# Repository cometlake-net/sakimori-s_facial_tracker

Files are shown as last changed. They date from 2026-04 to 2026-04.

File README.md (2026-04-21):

## License

This hardware design project (including schematics, PCB layout, and routing) is released under the **MIT License**. See the `LICENSE` file for details.

### Third-Party Assets / Acknowledgements

Some component libraries (schematic symbols, footprints, and 3D models) used in this project are provided by [SnapMagic](https://www.snapmagic.com/) (formerly SnapEDA). These specific asset files are licensed under the **Creative Commons Attribution-ShareAlike 4.0 International (CC-BY-SA 4.0)**. 
Please refer to their terms of service for further redistribution or modification of these library files.

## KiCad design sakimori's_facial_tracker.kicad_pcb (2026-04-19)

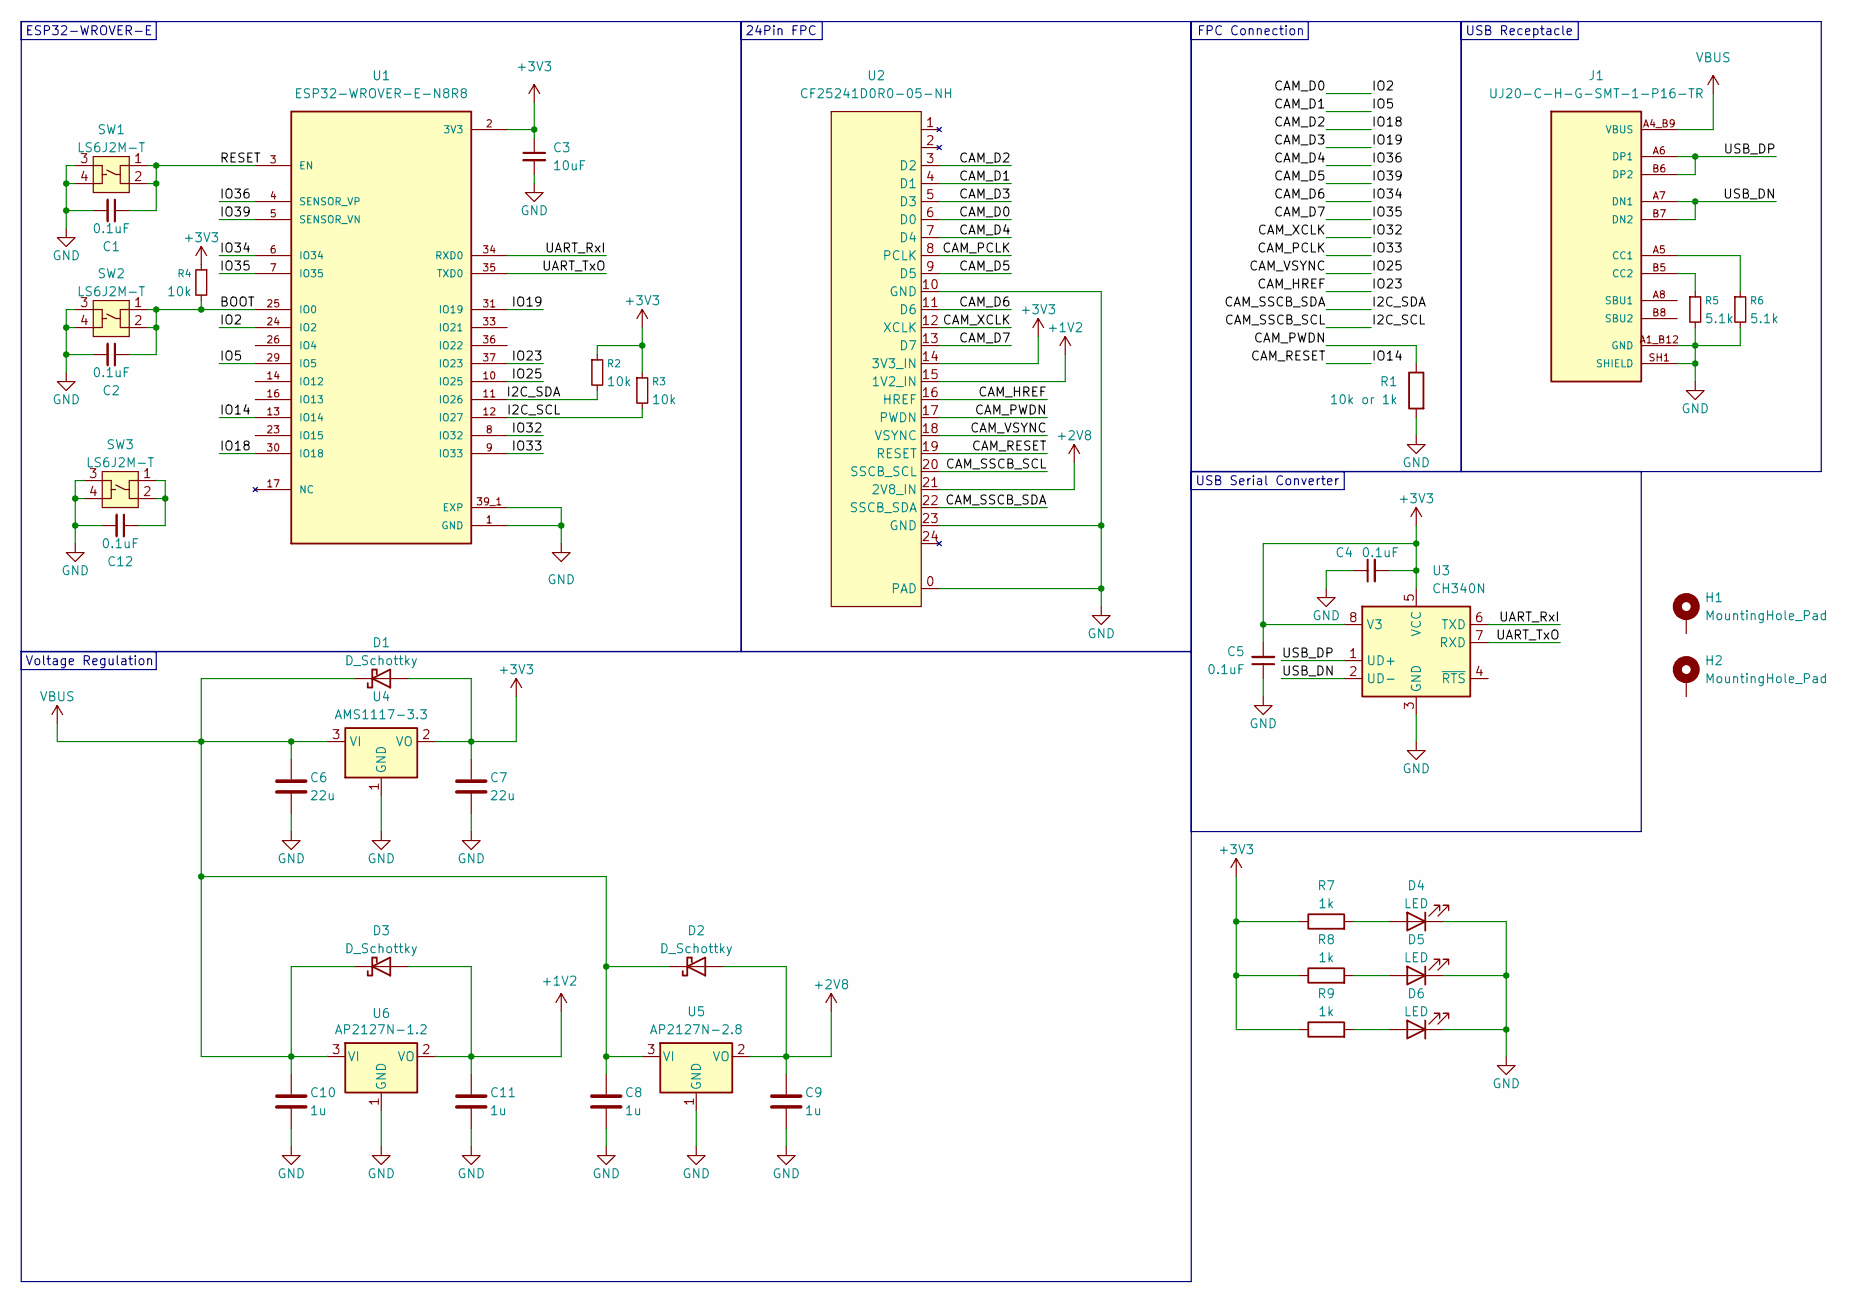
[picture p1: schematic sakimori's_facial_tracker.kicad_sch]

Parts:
C1, C2, C4, C5, C12: 0.1uF; C_0603_1608Metric
C3: 10uF; C_0603_1608Metric
C6, C7: 22u; C_0805_2012Metric
C8, C9, C10, C11: 1u; C_0603_1608Metric
D1, D2, D3: D_Schottky; D_SOD-123
D4, D5: LED; LED_1206_3216Metric
D6: LED; LED_0603_1608Metric
H1, H2: MountingHole_Pad; MountingHole_2.2mm_M2_Pad_TopBottom
J1: UJ20-C-H-G-SMT-1-P16-TR; SAMESKY_UJ20-C-H-G-SMT-1-P16-TR; PARTREV 1.0
R1: 10k or 1k; R_0603_1608Metric
R2, R3, R4: 10k; R_0603_1608Metric
R5, R6: 5.1k; R_0603_1608Metric
R7, R8, R9: 1k; R_0603_1608Metric
SW1, SW2, SW3: LS6J2M-T
U1: ESP32-WROVER-E-N8R8; PARTREV 1.6
U2: CF25241D0R0-05-NH
U3: CH340N; JEITA_SOIC-8_3.9x4.9mm_P1.27mm
U4: AMS1117-3.3; SOT-223-3_TabPin2
U5: AP2127N-2.8; SOT-23
U6: AP2127N-1.2; SOT-23

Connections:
+1V2: C11.1, D3.2 (A), U2.15 (1V2_IN), U6.2 (VO)
+2V8: C9.1, D2.2 (A), U2.21 (2V8_IN), U5.2 (VO)
+3V3: C3.1, C4.2, C5.2, C7.1, D1.2 (A), R2.1, R3.1, R4.1, R7.1, R8.1, R9.1, U1.2 (3V3), U2.14 (3V3_IN), U3.5 (VCC), U3.8 (V3), U4.2 (VO)
/BOOT: C2.1, R4.2, SW2.1, SW2.2, U1.25 (IO0)
/CAM_D0: U1.24 (IO2), U2.6 (D0)
/CAM_D1: U1.29 (IO5), U2.4 (D1)
/CAM_D2: U1.30 (IO18), U2.3 (D2)
/CAM_D3: U1.31 (IO19), U2.5 (D3)
/CAM_D4: U1.4 (SENSOR_VP), U2.7 (D4)
/CAM_D5: U1.5 (SENSOR_VN), U2.9 (D5)
/CAM_D6: U1.6 (IO34), U2.11 (D6)
/CAM_D7: U1.7 (IO35), U2.13 (D7)
/CAM_HREF: U1.37 (IO23), U2.16 (HREF)
/CAM_PCLK: U1.9 (IO33), U2.8 (PCLK)
/CAM_PWDN: R1.1, U2.17 (PWDN)
/CAM_RESET: U1.13 (IO14), U2.19 (RESET)
/CAM_SSCB_SCL: R3.2, U1.12 (IO27), U2.20 (SSCB_SCL)
/CAM_SSCB_SDA: R2.2, U1.11 (IO26), U2.22 (SSCB_SDA)
/CAM_VSYNC: U1.10 (IO25), U2.18 (VSYNC)
/CAM_XCLK: U1.8 (IO32), U2.12 (XCLK)
/RESET: C1.1, SW1.1, SW1.2, U1.3 (EN)
/UART_RxI: U1.34 (RXD0), U3.6 (TXD)
/UART_TxO: U1.35 (TXD0), U3.7 (RXD)
/USB_DN: J1.A7 (DN1), J1.B7 (DN2), U3.2 (UD-)
/USB_DP: J1.A6 (DP1), J1.B6 (DP2), U3.1 (UD+)
GND: C1.2, C2.2, C3.2, C4.1, C5.1, C6.2, C7.2, C8.2, C9.2, C10.2, C11.2, C12.2, D4.1 (K), D5.1 (K), D6.1 (K), J1.A1_B12 (GND), J1.B1_A12 (GND), J1.SH1 (SHIELD), J1.SH2 (SHIELD), J1.SH3 (SHIELD), J1.SH4 (SHIELD), R1.2, R5.2, R6.2, SW1.3, SW1.4, SW2.3, SW2.4, SW3.3, SW3.4, U1.1 (GND), U1.15 (GND), U1.38 (GND), U1.39_1 (EXP), U1.39_2 (EXP), U1.39_3 (EXP), U1.39_4 (EXP), U1.39_5 (EXP), U1.39_6 (EXP), U1.39_7 (EXP), U1.39_8 (EXP), U1.39_9 (EXP), U2.0 (PAD), U2.10 (GND), U2.23 (GND), U3.3 (GND), U4.1 (GND), U5.1 (GND), U6.1 (GND)
unnamed: C12.1, SW3.1, SW3.2
unnamed: D4.2 (A), R7.2
unnamed: D5.2 (A), R8.2
unnamed: D6.2 (A), R9.2
unnamed: J1.A5 (CC1), R6.1
unnamed: J1.B5 (CC2), R5.1
VBUS: C6.1, C8.1, C10.1, D1.1 (K), D2.1 (K), D3.1 (K), J1.A4_B9 (VBUS), J1.B4_A9 (VBUS), U4.3 (VI), U5.3 (VI), U6.3 (VI)

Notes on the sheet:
Voltage Regulation
24Pin FPC
USB Serial Converter
FPC Connection
USB Receptacle
ESP32-WROVER-E

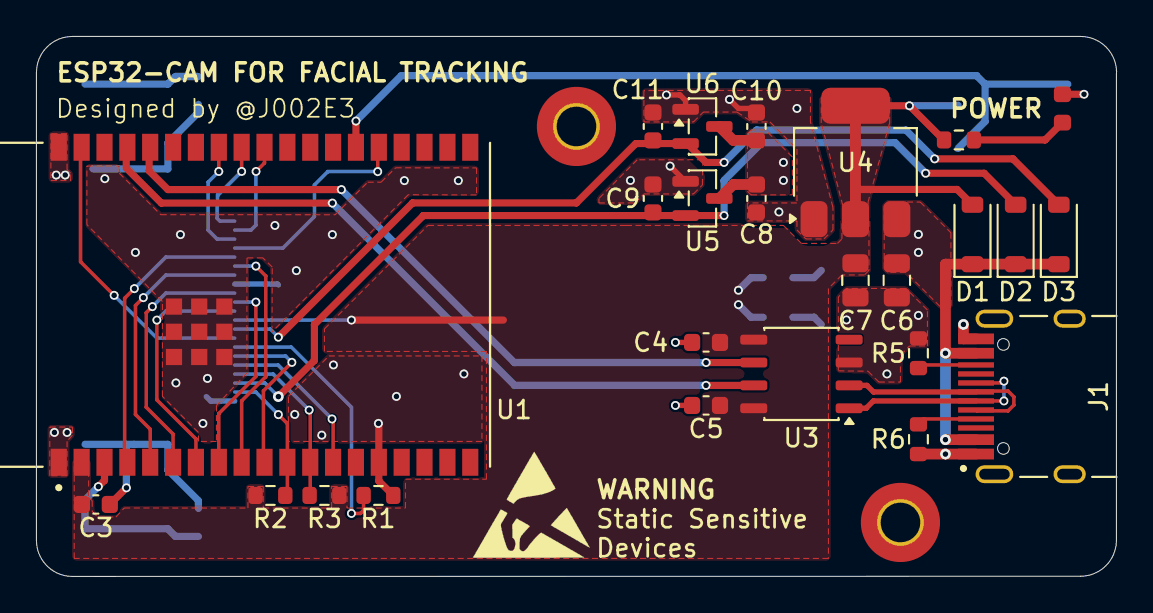
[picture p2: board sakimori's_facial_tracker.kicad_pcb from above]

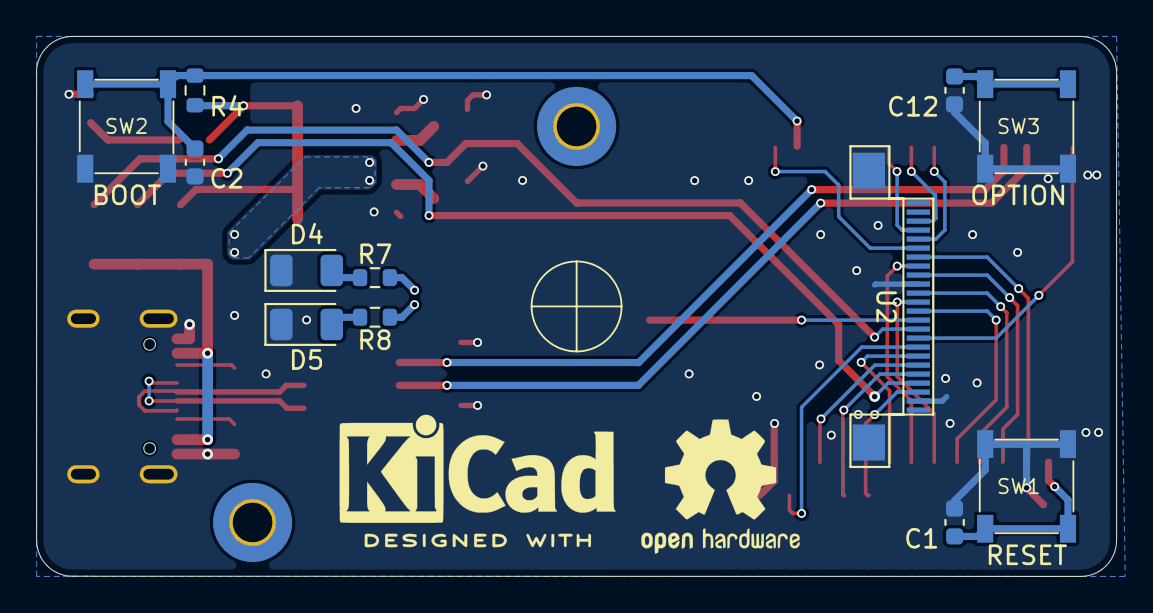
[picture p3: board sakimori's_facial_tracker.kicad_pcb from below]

Board: 2 copper layers, 60.0 x 30.0 mm, 39 parts (12 on the bottom side), 33 nets.
